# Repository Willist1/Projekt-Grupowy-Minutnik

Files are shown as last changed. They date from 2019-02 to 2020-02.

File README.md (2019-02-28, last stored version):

## Projekt Grupowy Minutnika dla prelegentów

Zadania stawiane porjektowi według strony projektów grupowych:

https://projektgrupowy.eti.pg.gda.pl/editions/12/projects/3469

 5@KSME'2019 Minutnik do odmierzania czasu prezentacji 1-99 minut

edycja: 2019

klient: dr hab. inż. Marek Wójcikowski prof. nadzw. PG (opiekun PG)

opiekun: dr hab. inż. Marek Wójcikowski prof. nadzw. PG (KSME)

kierownik: -

W ramach projektu powinien powstać projekt oraz prototyp
sprzętowego minutnika do odmierzania czasu trwania prezentacji. Wymagane cechy
urządzenia:

- odmierzanie czasu: 1-99 minut z rozdzielczością 1 sekundy;

- zasilanie bateryjne oraz 5V (USB), opcjonalnie akumulator z
ładowaniem w urządzeniu;

- duży i jasny wyświetlacz (wysokość cyfry >40mm);

- łatwe ustawianie czasu prezentacji;

- sygnalizacja dźwiękowa:

    - ostrzeżenie przed końcem prezentacji (czas wyprzedzenia
ustawiany przez użytkownika);

    - zakończenia prezentacji;

    - możliwość wyłączenia sygnalizacji ostrzeżenia raz
zakończenia;

- pamięć ustawień po wyłączeniu zasilania;

- kompaktowe rozmiary;

- atrakcyjny wygląd.

 Zakres pracy:

- zapoznanie się z istniejącymi rozwiązaniami i dostępnymi
wyświetlaczami;

- do realizacji minutnika można wykorzystać gotowy moduł
mikrokontrolera;

- zapoznanie się z istniejącymi mikrokontrolerami;

- opracowanie interfejsu użytkownika;

- napisanie oprogramowania mikrokontrolera;

- wykonanie i uruchomienie prototypu urządzenia;

- zaprojektowanie i wykonanie obudowy (np. w technologii druku
3D);

- napisanie dokumentacji.

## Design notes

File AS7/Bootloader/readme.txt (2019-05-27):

'breadboard' folder should be placed in:
C:\Program Files (x86)\Arduino\hardware

using AVRdude 6.3

To burn bootloader:
- connect USBasp to ATmega
- run 'NormalFuses'
- run 'BurnBootloader'

To upload program using bootloader:
- turn off supply voltage of ATmega
- draw PD7 to ground
- turn on supply voltage of ATmega
- run 'ArduinoBootloader'
- shortly after that set PD7 high

useful links:
- ATmega on breadboard: https://forum.mysensors.org/topic/3018/tutorial-how-to-burn-1mhz-8mhz-bootloader-using-arduino-ide-1-6-5-r5
- Verbose output on upload: https://forum.arduino.cc/index.php?topic=417659.0

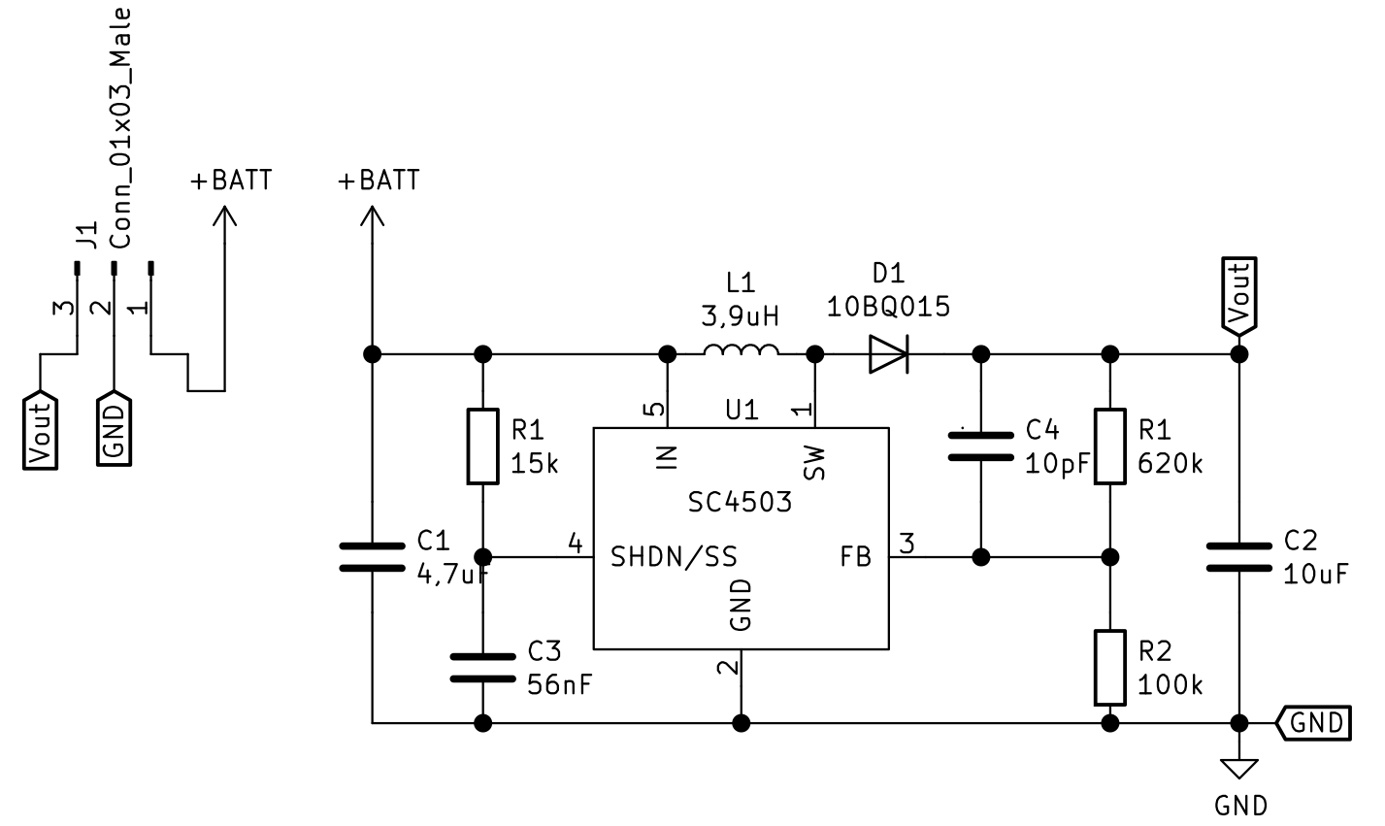
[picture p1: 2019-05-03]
Minutnix/BoostSchematic7V.png

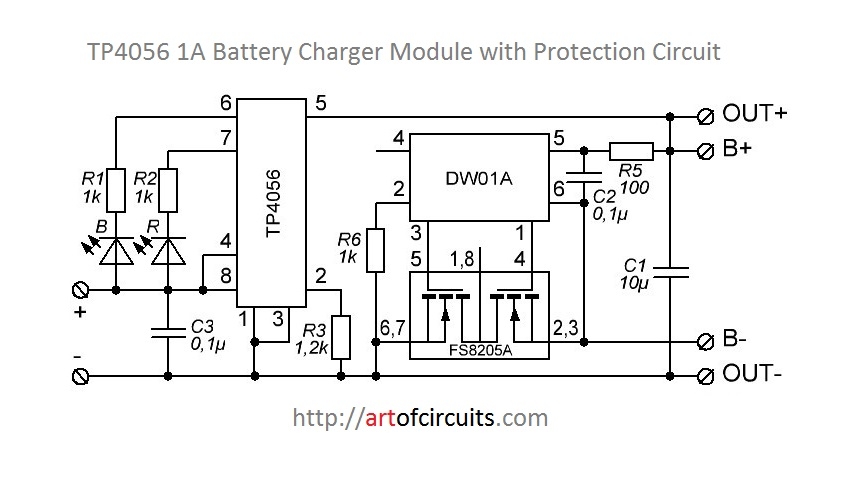
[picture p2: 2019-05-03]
Minutnix/ChargerSchematic.jpg

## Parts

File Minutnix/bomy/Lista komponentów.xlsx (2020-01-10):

Lista komponentów
Część | Package | Wartość/Model | Ilość
Rezystor | R0603 | 51 [Ω] | 30
Kondensator | C0603 | 100 n [F] | 11
Rezystor | R0603 | 1.2 k [Ω] | 1
Rezystor | R0603 | 4.7 k [Ω] | 11
Rezystor | R0603 | 220 [Ω] | 2
Kondensator | C0603 | 22 p [F] | 2
Kondensator | C1210 | 100 u [F] | 1
Rezystor | R0603 | 10 k [Ω] | 1
Kondensator | C0402 | 10 n [F] | 1
Kondensator | C1206 | 10 u [F] | 2
Dławik | DR73 | 10 u [H] | 1
Kondensator | SMC_B | 4.7 u [F] | 1
Kondensator | 153CLV-0810 | 470 u [F] | 1
Rezystor | R0603 | 820 [Ω] | 7
Dławik ferrytowy | R0604 | 100MHz: 330Ω | 1
Konektor | JST-XH-03 |  | 3
Konektor | FFC-0.5mm-12pin |  | 2
Wyświetlacz 7 segm. | OPD-S23010LR-BW |  | 4
Kwarc | SMD-2X6-CYL | 32.768 k [Hz] | 1
Przycisk | TACTILE_SWITCH_PTH_12MM |  | 5
Rejestr przesuwny | SO16 | TPIC6C596PW | 4
Dioda led | CHIPLED_0603 | zielona | 2
Dioda led | CHIPLED_0603 | czerwona | 2
Dioda led | CHIPLED_0603 | żółta | 3
Dioda led | LED5MM | czerwona | 2
Włącznik | mini isostat |  | 1
Regulator | SOT223 | LM1117 | 1
Regulator | Pololu 9 V regulator board | U3V12F9 | 1
Tranzystor | SOT23 | NPN | 1
Dioda Shottky | DO214AA |  | 1
Fotorezystor | GL5528 | 10-20 k [Ω] | 1
Złącze ISP | MA03-2 |  | 1
Potencjometr | Helitrim 3296Y | 10 k [Ω] | 1
Brzęczyk | HCM12 | 85 [dB] | 1
Enkoder | EC11 pionowy | 20 [imp/obr] | 1
Port microUSB | AUSB-1010-05S | typ B | 1
Kontroler | QFP80P900X900X120-32N | ATMEGA328P-AU | 1
Kontroler USB-UART | SSOP28 | FT232RL | 1
Ekspander | SO16W | PCF8574T | 1
Ładowarka | SOP-8 | TP4056 | 1

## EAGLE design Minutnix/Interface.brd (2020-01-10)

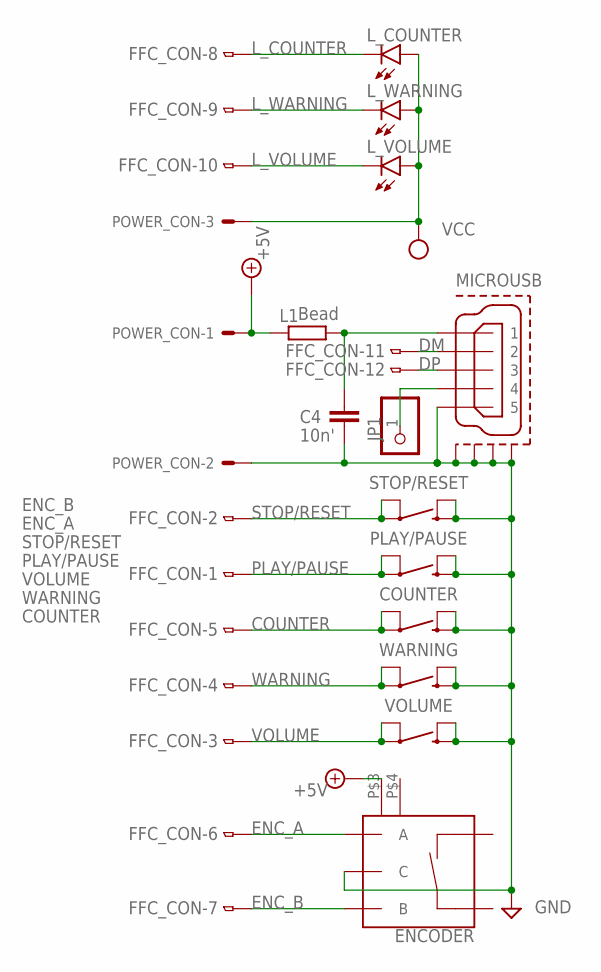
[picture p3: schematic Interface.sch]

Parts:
C4: 10n'; C0402
COUNTER: MOMENTARY-SWITCH-SPST-PTH-12MM; TACTILE_SWITCH_PTH_12MM
ENCODER: ENCODER-SWITCH; ROTARY_ENC_PLAIN
FFC_CON: FH12-12S-0.5S_THINNER; FH12-12S-0.5SH_THINER
JP1: PINHD-1X1; 1X01
L1: Bead; R0603
L_COUNTER: LEDCHIPLED_0805; CHIPLED_0805
L_VOLUME: LEDCHIPLED_0805; CHIPLED_0805
L_WARNING: LEDCHIPLED_0805; CHIPLED_0805
MICROUSB: MICRO-USB-RECEPTACLE; 47589-0002
PLAY/PAUSE: MOMENTARY-SWITCH-SPST-PTH-12MM; TACTILE_SWITCH_PTH_12MM
POWER_CON: JST-XH-03-PIN-LONG-PAD; JST-XH-03-PACKAGE-LONG-PAD
STOP/RESET: MOMENTARY-SWITCH-SPST-PTH-12MM; TACTILE_SWITCH_PTH_12MM
VOLUME: MOMENTARY-SWITCH-SPST-PTH-12MM; TACTILE_SWITCH_PTH_12MM
WARNING: MOMENTARY-SWITCH-SPST-PTH-12MM; TACTILE_SWITCH_PTH_12MM

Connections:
+5V: ENCODER.P$3 (GND1), L1.1, POWER_CON.1
COUNTER: COUNTER.1, COUNTER.2 (3), FFC_CON.5
DM: FFC_CON.11, MICROUSB.2
DP: FFC_CON.12, MICROUSB.3
ENC_A: ENCODER.A, FFC_CON.6
ENC_B: ENCODER.B, FFC_CON.7
GND: C4.2, COUNTER.3 (2), COUNTER.4, ENCODER.C, MICROUSB.5, MICROUSB.CASING1 (GND1), MICROUSB.CASING2 (GND2), MICROUSB.CASING3 (GND3), MICROUSB.CASING4 (GND4), PLAY/PAUSE.3 (2), PLAY/PAUSE.4, POWER_CON.2, STOP/RESET.3 (2), STOP/RESET.4, VOLUME.3 (2), VOLUME.4, WARNING.3 (2), WARNING.4
L_COUNTER: FFC_CON.8, L_COUNTER.C
L_VOLUME: FFC_CON.10, L_VOLUME.C
L_WARNING: FFC_CON.9, L_WARNING.C
unnamed: JP1.1, MICROUSB.4
unnamed: C4.1, L1.2, MICROUSB.1
PLAY/PAUSE: FFC_CON.1, PLAY/PAUSE.1, PLAY/PAUSE.2 (3)
STOP/RESET: FFC_CON.2, STOP/RESET.1, STOP/RESET.2 (3)
VCC: L_COUNTER.A, L_VOLUME.A, L_WARNING.A, POWER_CON.3
VOLUME: FFC_CON.3, VOLUME.1, VOLUME.2 (3)
WARNING: FFC_CON.4, WARNING.1, WARNING.2 (3)

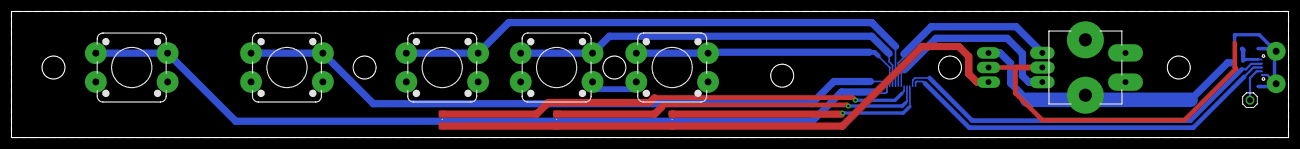
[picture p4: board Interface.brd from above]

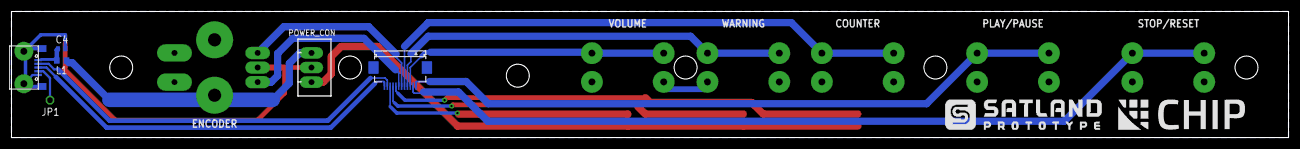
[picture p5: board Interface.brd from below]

Board: 2 copper layers, 222.3 x 21.9 mm, 15 parts (5 on the bottom side), 17 nets.

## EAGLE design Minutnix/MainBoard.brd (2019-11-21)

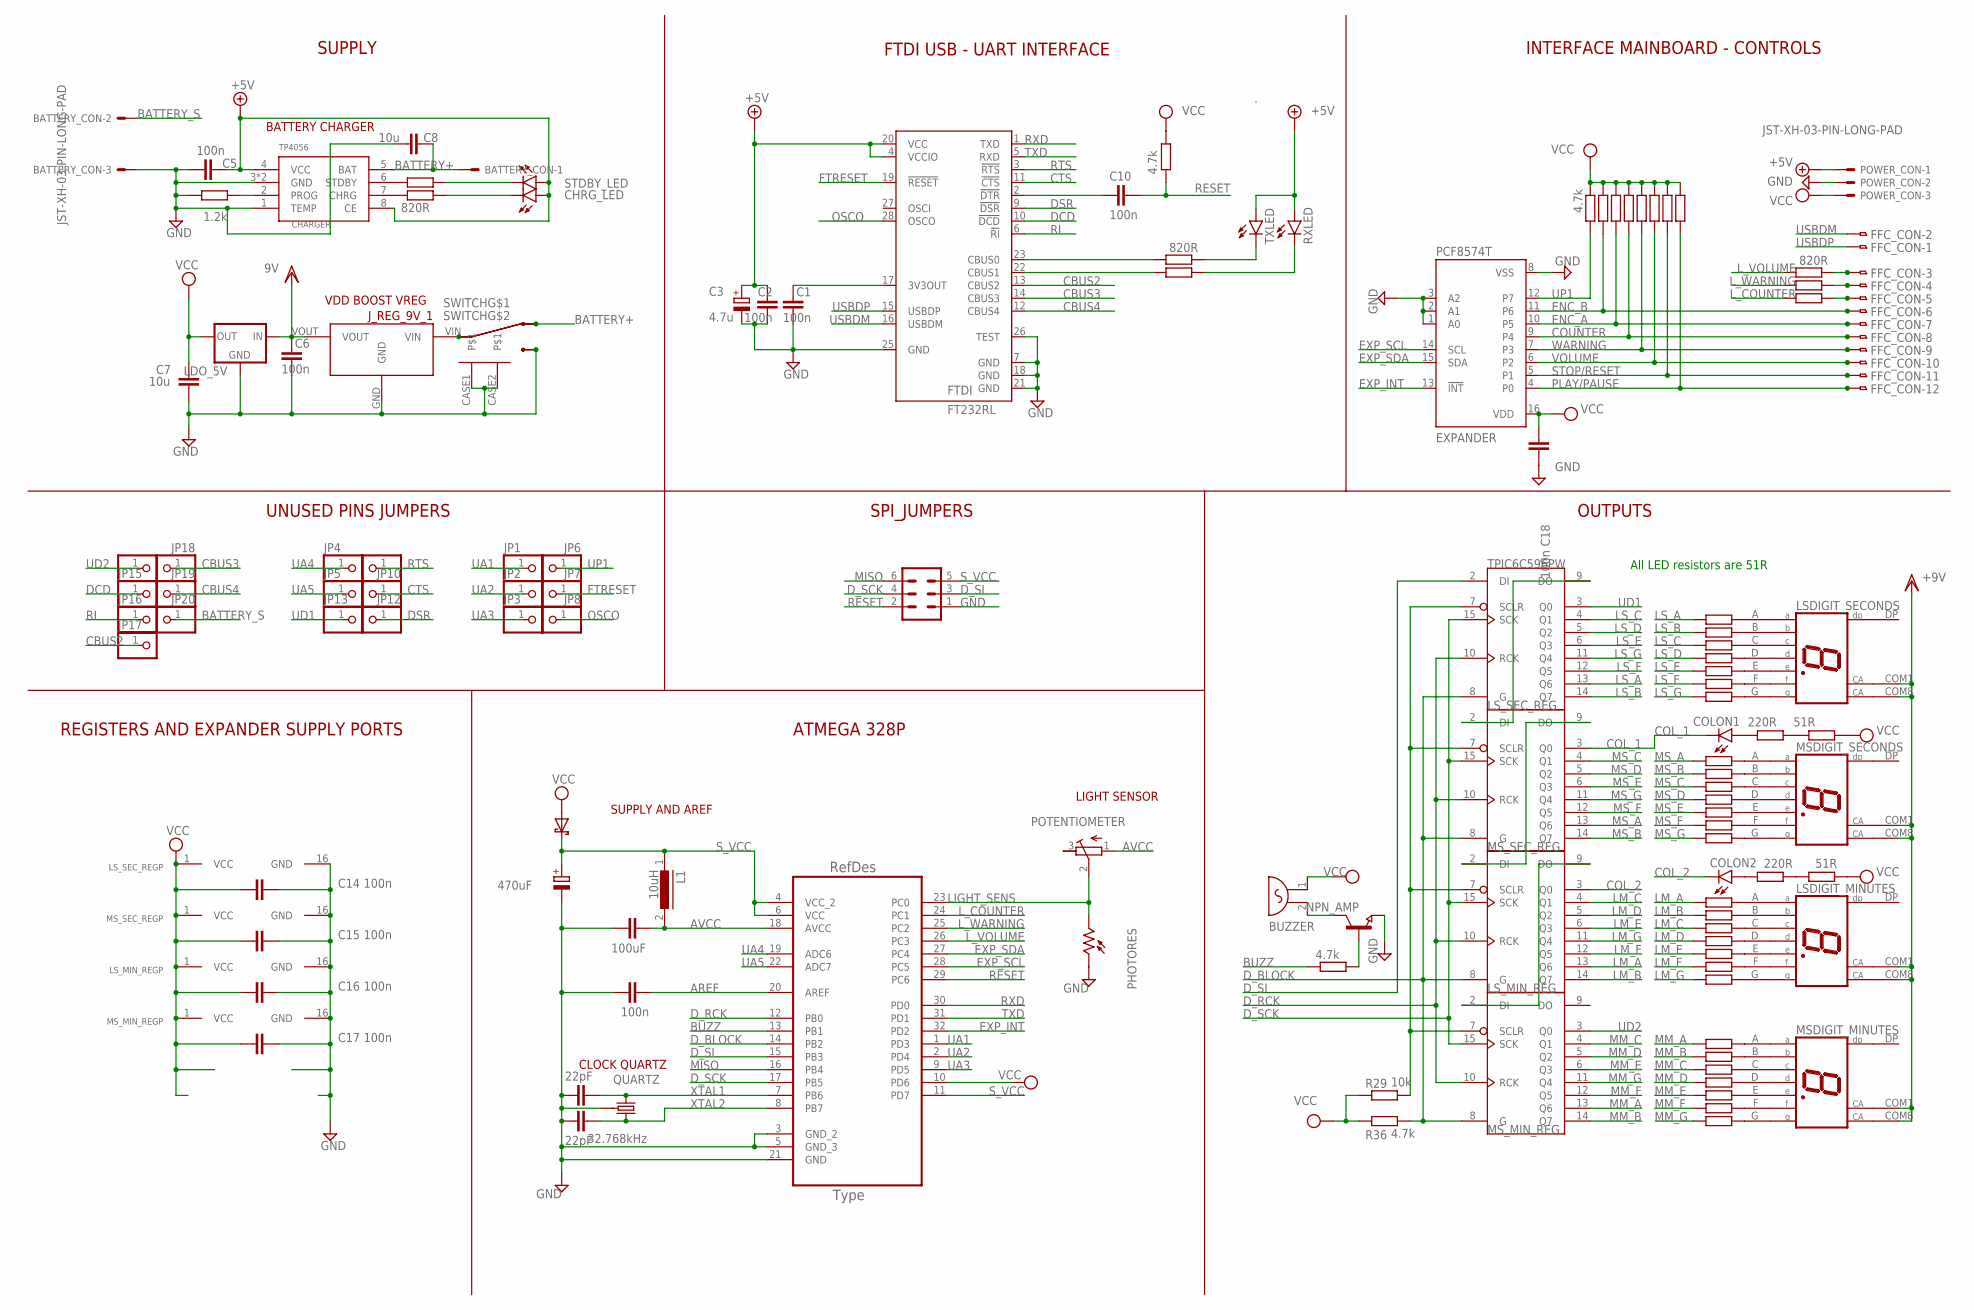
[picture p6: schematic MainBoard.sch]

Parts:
ATMEGA328P: ATMEGA328P-AU; QFP80P900X900X120-32N
BATTERY_CON: JST-XH-03-PIN-LONG-PAD; JST-XH-03-PACKAGE-LONG-PAD
BUZZER: F/HGP
C1, C2, C4, C5, C6, C10, C14, C15, C16, C17, C18: 100n; C0603
C3: 4.7u; SMC_B
C7, C8: 10u; C1206
C29, C30: 22pF; C0603
C31: 470uF; 153CLV-0810
C32: 100uF; C1210
CHARGER: TP4056; SOP-8
CHRG_LED: LEDCHIPLED_0603; CHIPLED_0603
COLON1, COLON2: LED5MM
EXPANDER: PCF8574T; SO16W
FFC_CON: FH12-12S-0.5S_THINNER; FH12-12S-0.5SH_THINER
FTDI: FT232RL; SSOP28
JP1, JP2, JP3, JP4, JP5, JP6, JP7, JP8, JP9, JP10, JP12, JP13, JP14, JP15, JP16, JP17, JP18, JP19, JP20: PINHD-1X1; 1X01
J_REG_9V_1: 9V_VOLTAGE_REGULATOR
L1: 10uH; DR73
LDO_5V: LM1117; SOT223
LSDIGIT_MINUTES: LED-7-SEGM-56MM; MYTHT
LSDIGIT_SECONDS: LED-7-SEGM-56MM; MYTHT
LS_MIN_REG: TPIC6C596PW; SO16
LS_SEC_REG: TPIC6C596PW; SO16
MSDIGIT_MINUTES: LED-7-SEGM-56MM; MYTHT
MSDIGIT_SECONDS: LED-7-SEGM-56MM; MYTHT
MS_MIN_REG: TPIC6C596PW; SO16
MS_SEC_REG: TPIC6C596PW; SO16
NPN_AMP: NPN-TRANSISTOR_SOT23; SOT23
PHOTORES: VT90N1; VT900
POTENTIOMETER: R-TRIMM3296Y; RTRIM3296Y
POWER_CON: JST-XH-03-PIN-LONG-PAD; JST-XH-03-PACKAGE-LONG-PAD
QUARTZ: 32.768kHz; CRYSTAL-SMD-2X6-CYL
R1, R2, R3, R4, R5, R6, R7, R8, R9, R10, R11, R12, R13, R14, R15, R16, R17, R18, R19, R20, R21, R22, R23, R24, R25, R26, R27, R28: 50; R0603
R29: 10k; R0603
R30, R31, R33, R36, R42, R43, R44, R45, R46, R56, R61: 4.7k; R0603
R32, R35: 51R; R0603
R34, R50: 220R; R0603
R39, R40, R47, R52, R64, R65, R66: 820R; R0603
R48: 1.2k; R0603
RXLED: LEDCHIPLED_0603; CHIPLED_0603
SHOTTKY: S2A; DO214AA
SPI_JUMPERS: MA03-2
STDBY_LED: LEDCHIPLED_0603; CHIPLED_0603
SWITCH: X2; MINI
TXLED: LEDCHIPLED_0603; CHIPLED_0603

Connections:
+5V: C2.2, C3.+, C5.1, CHARGER.4 (VCC), CHARGER.8 (CE), CHRG_LED.A, FTDI.4 (VCCIO), FTDI.20 (VCC), POWER_CON.1, RXLED.A, STDBY_LED.A, TXLED.A
AREF: ATMEGA328P.20 (AREF), C4.1
AVCC: ATMEGA328P.18 (AVCC), C32.1, L1.2, POTENTIOMETER.1 (A)
BATTERY+: BATTERY_CON.1, C8.2, CHARGER.5 (BAT), SWITCH.1, SWITCH.4
BATTERY_S: BATTERY_CON.2, JP20.1
BUZZ: ATMEGA328P.13 (PB1), R30.2
CBUS2: FTDI.13 (CBUS2), JP17.1
CBUS3: FTDI.14 (CBUS3), JP18.1
CBUS4: FTDI.12 (CBUS4), JP19.1
COL_1: COLON1.K (C), MS_SEC_REG.3 (Q0)
COL_2: COLON2.K (C), LS_MIN_REG.3 (Q0)
COUNTER: EXPANDER.9 (P4), FFC_CON.8, R42.2
CTS: FTDI.11 (!CTS), JP10.1
DCD: FTDI.10 (!DCD), JP15.1
DSR: FTDI.9 (!DSR), JP12.1
DTR: C10.2, FTDI.2 (!DTR)
D_BLOCK: ATMEGA328P.14 (PB2), LS_MIN_REG.8 (G), LS_SEC_REG.8 (G), MS_MIN_REG.8 (G), MS_SEC_REG.8 (G), R36.1
D_RCK: ATMEGA328P.12 (PB0), LS_MIN_REG.10 (RCK), LS_SEC_REG.10 (RCK), MS_MIN_REG.10 (RCK), MS_SEC_REG.10 (RCK)
D_SCK: ATMEGA328P.17 (PB5), LS_MIN_REG.15 (SCK), LS_SEC_REG.15 (SCK), MS_MIN_REG.15 (SCK), MS_SEC_REG.15 (SCK), SPI_JUMPERS.4
D_SI: ATMEGA328P.15 (PB3), LS_SEC_REG.2 (DI), SPI_JUMPERS.3
ENC_A: EXPANDER.10 (P5), FFC_CON.7, R33.2
ENC_B: EXPANDER.11 (P6), FFC_CON.6, R31.2
EXP_INT: ATMEGA328P.32 (PD2), EXPANDER.13 (!INT)
EXP_SCL: ATMEGA328P.28 (PC5), EXPANDER.14 (SCL)
EXP_SDA: ATMEGA328P.27 (PC4), EXPANDER.15 (SDA)
FTRESET: FTDI.19 (!RESET), JP7.1
GND: ATMEGA328P.3 (GND_2), ATMEGA328P.5 (GND_3), ATMEGA328P.21 (GND), BATTERY_CON.3, C1.1, C2.1, C3.-, C4.2, C5.2, C6.1, C7.2, C8.1, C14.1, C15.1, C16.1, C17.1, C18.1, C29.1, C30.1, C31.-, C32.2, CHARGER.1 (TEMP), CHARGER.3 (GND), CHARGER.ETP (GND), EXPANDER.1 (A0), EXPANDER.2 (A1), EXPANDER.3 (A2), EXPANDER.8 (VSS), FTDI.7 (GND), FTDI.18 (GND), FTDI.21 (GND), FTDI.25 (GND), FTDI.26 (TEST), J_REG_9V_1.GND, LDO_5V.1 (GND), LS_MIN_REG.16 (GND), LS_SEC_REG.16 (GND), MS_MIN_REG.16 (GND), MS_SEC_REG.16 (GND), NPN_AMP.2 (E), PHOTORES.1, POWER_CON.2, QUARTZ.SHEILD (GND), R48.2, SPI_JUMPERS.1, SWITCH.3, SWITCH.6, SWITCH.CASE1, SWITCH.CASE2
LIGHT_SENS: ATMEGA328P.23 (PC0), PHOTORES.2, POTENTIOMETER.2 (S)
LM_A: LS_MIN_REG.13 (Q6), R7.2
LM_B: LS_MIN_REG.14 (Q7), R6.2
LM_C: LS_MIN_REG.4 (Q1), R5.2
LM_D: LS_MIN_REG.5 (Q2), R4.2
LM_E: LS_MIN_REG.6 (Q3), R3.2
LM_F: LS_MIN_REG.12 (Q5), R2.2
LM_G: LS_MIN_REG.11 (Q4), R1.2
LS_A: LS_SEC_REG.13 (Q6), R21.2
LS_B: LS_SEC_REG.14 (Q7), R20.2
LS_C: LS_SEC_REG.4 (Q1), R19.2
LS_D: LS_SEC_REG.5 (Q2), R18.2
LS_E: LS_SEC_REG.6 (Q3), R17.2
LS_F: LS_SEC_REG.12 (Q5), R16.2
LS_G: LS_SEC_REG.11 (Q4), R15.2
L_COUNTER: ATMEGA328P.24 (PC1), R52.2
L_VOLUME: ATMEGA328P.26 (PC3), R64.2
L_WARNING: ATMEGA328P.25 (PC2), R47.2
MISO: ATMEGA328P.16 (PB4), SPI_JUMPERS.6
MM_A: MS_MIN_REG.13 (Q6), R27.2
MM_B: MS_MIN_REG.14 (Q7), R26.2
MM_C: MS_MIN_REG.4 (Q1), R25.2
MM_D: MS_MIN_REG.5 (Q2), R24.2
MM_E: MS_MIN_REG.6 (Q3), R23.2
MM_F: MS_MIN_REG.12 (Q5), R22.2
MM_G: MS_MIN_REG.11 (Q4), R28.2
MS_A: MS_SEC_REG.13 (Q6), R14.2
MS_B: MS_SEC_REG.14 (Q7), R13.2
MS_C: MS_SEC_REG.4 (Q1), R12.2
MS_D: MS_SEC_REG.5 (Q2), R11.2
MS_E: MS_SEC_REG.6 (Q3), R10.2
MS_F: MS_SEC_REG.12 (Q5), R9.2
MS_G: MS_SEC_REG.11 (Q4), R8.2
unnamed: R32.2, R50.1
unnamed: MSDIGIT_MINUTES.F, R22.1
unnamed: LSDIGIT_MINUTES.G, R1.1
unnamed: MSDIGIT_MINUTES.E, R23.1
unnamed: LSDIGIT_MINUTES.F, R2.1
unnamed: LSDIGIT_MINUTES.E, R3.1
unnamed: LSDIGIT_MINUTES.D, R4.1
unnamed: LSDIGIT_MINUTES.C, R5.1
unnamed: LSDIGIT_MINUTES.B, R6.1
unnamed: FFC_CON.3, R64.1
unnamed: MSDIGIT_MINUTES.D, R24.1
unnamed: FFC_CON.4, R47.1
unnamed: MSDIGIT_MINUTES.C, R25.1
unnamed: LS_MIN_REG.7 (SCLR), LS_SEC_REG.7 (SCLR), MS_MIN_REG.7 (SCLR), MS_SEC_REG.7 (SCLR), R29.1
unnamed: LSDIGIT_MINUTES.A, R7.1
unnamed: C1.2, FTDI.17 (3V3OUT)
unnamed: COLON2.A, R34.2
unnamed: FFC_CON.5, R52.1
unnamed: MSDIGIT_MINUTES.B, R26.1
unnamed: MSDIGIT_MINUTES.A, R27.1
unnamed: MSDIGIT_SECONDS.G, R8.1
unnamed: MSDIGIT_SECONDS.F, R9.1
unnamed: MSDIGIT_SECONDS.E, R10.1
unnamed: FTDI.23 (CBUS0), R66.2
unnamed: MSDIGIT_SECONDS.D, R11.1
unnamed: MSDIGIT_SECONDS.C, R12.1
unnamed: MSDIGIT_SECONDS.B, R13.1
unnamed: MSDIGIT_SECONDS.A, R14.1
unnamed: LSDIGIT_SECONDS.G, R15.1
unnamed: LSDIGIT_SECONDS.F, R16.1
unnamed: FTDI.22 (CBUS1), R65.2
unnamed: LSDIGIT_SECONDS.E, R17.1
unnamed: LSDIGIT_SECONDS.D, R18.1
unnamed: LSDIGIT_SECONDS.C, R19.1
unnamed: LSDIGIT_SECONDS.B, R20.1
unnamed: LSDIGIT_SECONDS.A, R21.1
unnamed: R34.1, R35.2
unnamed: CHARGER.7 (CHRG), R39.2
unnamed: CHARGER.6 (STDBY), R40.2
unnamed: CHRG_LED.C, R39.1
unnamed: R40.1, STDBY_LED.C
unnamed: COLON1.A, R50.2
unnamed: MSDIGIT_MINUTES.G, R28.1
unnamed: R66.1, TXLED.C
unnamed: NPN_AMP.1 (B), R30.1
unnamed: BUZZER.2, NPN_AMP.3 (C)
unnamed: R65.1, RXLED.C
unnamed: LS_MIN_REG.2 (DI), MS_SEC_REG.9 (DO)
unnamed: LS_MIN_REG.9 (DO), MS_MIN_REG.2 (DI)
unnamed: LS_SEC_REG.9 (DO), MS_SEC_REG.2 (DI)
unnamed: J_REG_9V_1.VIN, SWITCH.2, SWITCH.5
unnamed: CHARGER.2 (PROG), R48.1
OSCO: FTDI.28 (OSCO), JP8.1
PLAY/PAUSE: EXPANDER.4 (P0), FFC_CON.12, R46.2
RESET: ATMEGA328P.29 (PC6), C10.1, R56.1, SPI_JUMPERS.2
RI: FTDI.6 (!RI), JP16.1
RTS: FTDI.3 (!RTS), JP9.1
RXD: ATMEGA328P.30 (PD0), FTDI.1 (TXD)
STOP/RESET: EXPANDER.5 (P1), FFC_CON.11, R45.2
S_VCC: ATMEGA328P.4 (VCC_2), ATMEGA328P.6 (VCC), ATMEGA328P.11 (PD7), C31.+, L1.1, SHOTTKY.C, SPI_JUMPERS.5
TXD: ATMEGA328P.31 (PD1), FTDI.5 (RXD)
UA1: ATMEGA328P.1 (PD3), JP1.1
UA2: ATMEGA328P.2 (PD4), JP2.1
UA3: ATMEGA328P.9 (PD5), JP3.1
UA4: ATMEGA328P.19 (ADC6), JP4.1
UA5: ATMEGA328P.22 (ADC7), JP5.1
UD1: JP13.1, LS_SEC_REG.3 (Q0)
UD2: JP14.1, MS_MIN_REG.3 (Q0)
UP1: EXPANDER.12 (P7), JP6.1, R61.2
USBDM: FFC_CON.2, FTDI.16 (USBDM)
USBDP: FFC_CON.1, FTDI.15 (USBDP)
VCC: ATMEGA328P.10 (PD6), BUZZER.1, C7.1, C14.2, C15.2, C16.2, C17.2, C18.2, EXPANDER.16 (VDD), LDO_5V.2 (OUT), LDO_5V.4 (OUT), LS_MIN_REG.1 (VCC), LS_SEC_REG.1 (VCC), MS_MIN_REG.1 (VCC), MS_SEC_REG.1 (VCC), POWER_CON.3, R29.2, R31.1, R32.1, R33.1, R35.1, R36.2, R42.1, R43.1, R44.1, R45.1, R46.1, R56.2, R61.1, SHOTTKY.A
VDD: C6.2, J_REG_9V_1.VOUT, LDO_5V.3 (IN), LSDIGIT_MINUTES.COM1 (CA1), LSDIGIT_MINUTES.COM8 (CA8), LSDIGIT_SECONDS.COM1 (CA1), LSDIGIT_SECONDS.COM8 (CA8), MSDIGIT_MINUTES.COM1 (CA1), MSDIGIT_MINUTES.COM8 (CA8), MSDIGIT_SECONDS.COM1 (CA1), MSDIGIT_SECONDS.COM8 (CA8)
VOLUME: EXPANDER.6 (P2), FFC_CON.10, R44.2
WARNING: EXPANDER.7 (P3), FFC_CON.9, R43.2
XTAL1: ATMEGA328P.7 (PB6), C29.2, QUARTZ.X2 (2)
XTAL2: ATMEGA328P.8 (PB7), C30.2, QUARTZ.X1 (1)

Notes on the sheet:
All LED resistors are 51R
LIGHT SENSOR
INTERFACE MAINBOARD - CONTROLS
FTDI USB - UART INTERFACE
UNUSED PINS JUMPERS
SUPPLY AND AREF
CLOCK QUARTZ
VDD BOOST VREG
REGISTERS AND EXPANDER SUPPLY PORTS
BATTERY CHARGER
SUPPLY
ATMEGA 328P
OUTPUTS

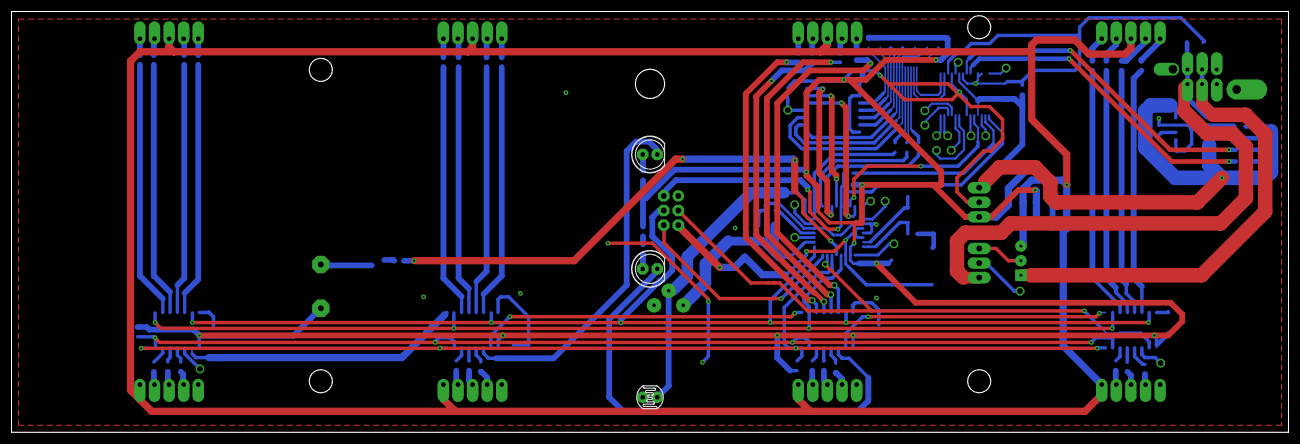
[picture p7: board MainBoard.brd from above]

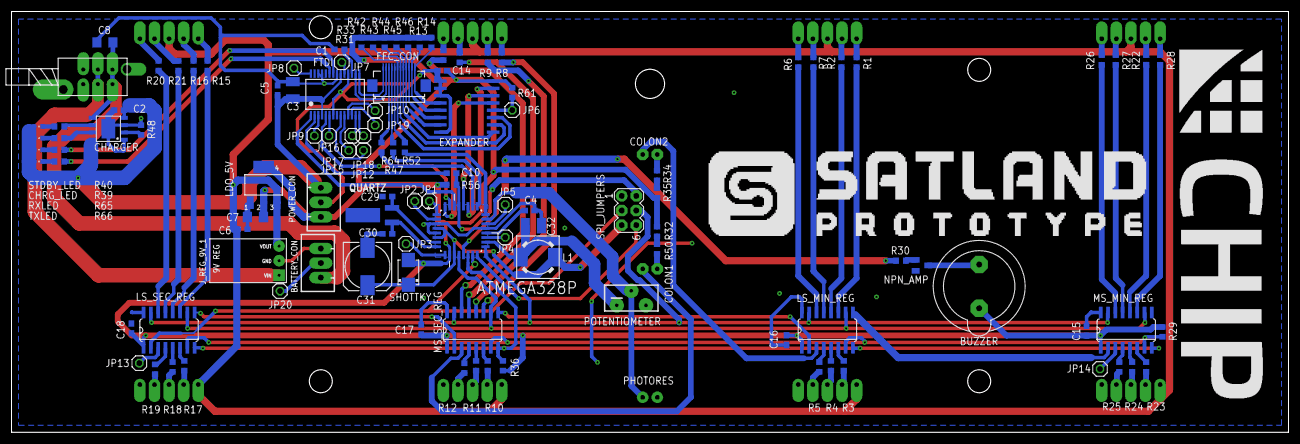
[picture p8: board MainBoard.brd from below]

Board: 2 copper layers, 222.3 x 73.3 mm, 121 parts (114 on the bottom side), 137 nets.

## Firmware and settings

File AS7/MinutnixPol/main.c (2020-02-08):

/*
 *  main.c
 *
 *  Created: 2019-03-09 15:34
 *  Authors: Kluczek, Wegrzyn, Jopek
 */ 
//#define F_CPU 8000000L

#include <avr/io.h>
#include <avr/interrupt.h>
#include <avr/sleep.h>
#include <avr/wdt.h>
#include <util/delay.h>
#include <util/atomic.h>
#include <avr/pgmspace.h>
#include <stdbool.h>
#include <stdio.h>
#include "main.h"
#include "uart.h"
#include "display.h"
#include "i2c.h"
#include "PCF8574.h"
#include "encoder.h"
#include "buzzer.h"
#include "pwrFail.h"
#include "TPIC6C596.h"
#include "lightsensor.h"


#define EXTERNAL_CLOCK

#ifdef EXTERNAL_CLOCK
#define MAX_NO_ACTIVITY_TICKS 600	// 5 min
#else
#define MAX_NO_ACTIVITY_TICKS 300000	// 5 min
#endif

tSTATE currentState = sSetting;
volatile uint32_t ticks = 0;
volatile uint8_t toggle_500ms = 0;
uint32_t lastActivityTime = 0;
uint8_t WARN_MAX_VAL = 15;

#define ALARM_MAX_DURATION 20 // [s]
volatile uint8_t alarmTick = 0;
volatile bool endBeep = false;

// index of brightnessTable is ADC reading (max 255) divided by 9
// results range: 0-28 (29 values)
#define ADC_READING_DIVISOR 9
const uint8_t __attribute__((__progmem__)) brightnessTable[] = {
	//100, 55, 35, 30, 26, 24, 22, 20, 19, 18, 17, 16, 15, 14, 9, 5, 2, 1, 1, 1
	100, 70, 55, 42, 35, 33, 30, 28, 26, 25, 24, 23, 22, 21, 20, 19, 18, 17, 16, 15, 14, 13, 8, 5, 2, 1, 1, 1, 1
};

void sysTickInit()
{
	#ifdef EXTERNAL_CLOCK
	ASSR |= _BV(AS2);		// TIM2 tacted asynchronously
	TCCR2B = _BV(CS22);		// Preskaler CLKIO/64  (32.768 kHz / 256 / 64 = 2 Hz)
	#else //internal
	TCCR2A = _BV(WGM20);	//PWM, Phase Correct TOP = OCRA, OVint at BOTTOM
	OCR2A = 124;
	TCCR2B = _BV(WGM22) | _BV(CS21) | _BV(CS20);	// Preskaler CLKIO/32  (8 MHz / (124+1) / 32 /2 = 1 kHz)
	#endif
	
	while(ASSR & 0x1F);		// Wait for TIM2 update (busy flags must be cleared)
	TIMSK2 |= _BV(TOIE2);	// Unblock TIM2 overflow interrupt
}

void sysTickOn()
{
	TIMSK2 |= _BV(TOIE2);	// Unblock TIM2 overflow interrupt
}

void sysTickOff()
{
	TIMSK2 &= ~_BV(TOIE2);	// Block TIM2 overflow interrupt
}

ISR(TIMER2_OVF_vect)	// System clock
{
	ticks++;
	
	#ifdef EXTERNAL_CLOCK
	toggle_500ms ^= 0x01;
	if (!(ticks % 2) && (currentState == sRunning)) {
		if(NVData.totalSeconds > 0) NVData.totalSeconds--;
		if(endBeep && (alarmTick < ALARM_MAX_DURATION)) alarmTick++;
	}
	#else
	if (!(ticks % 500)) {
		toggle_500ms ^= 0x01;
	}
	if (!(ticks % 1000) && (currentState == sRunning)) {
		if(NVData.totalSeconds > 0) NVData.totalSeconds--;
		if(endBeep && (alarmTick < ALARM_MAX_DURATION)) alarmTick++;
	}
	#endif
	
	// ADJUST BRIGHTNESS
	uint8_t brightness = 0;
	memcpy_P(&brightness,brightnessTable+(lightsensorRead()/ADC_READING_DIVISOR),1);
	brightness = lightsensorFilter(brightness);
	displaySetBrightness(brightness);
}

void wdtInit() {
	MCUSR &= ~_BV(WDRF);	// Clear watchdog system reset flag
	wdt_reset();
	WDTCSR = _BV(WDCE) | _BV(WDE);
	wdt_enable(WDTO_1S);
}

void wdtDeinit() {
	MCUSR &= ~_BV(WDRF);
	wdt_reset();
	wdt_disable();
}

#define SETTINGS_LED_PORT PORTC
#define LED_SET_CNT 1
#define LED_SET_WARN 2
#define LED_SET_VOL 3

void settingsLEDInit() {
	DDRC |= (_BV(LED_SET_CNT) | _BV(LED_SET_WARN) | _BV(LED_SET_VOL));	// LED pins as output
	PORTC |= (_BV(LED_SET_CNT) | _BV(LED_SET_WARN) | _BV(LED_SET_VOL));	// Set all pins high (turn off LEDs)
}

void settingsLEDTurnOff() {
	PORTC |= (_BV(LED_SET_CNT) | _BV(LED_SET_WARN) | _BV(LED_SET_VOL));	// Turn off all LEDs
}

void settingsLEDToggle(uint8_t LEDId) {
	settingsLEDTurnOff();
	if (LEDId >= LED_SET_CNT && LEDId <= LED_SET_VOL) PORTC &= ~_BV(LEDId);	// Turn given LED on
}


BUTTON pressedButton = BUTTON_NONE;
BUTTON memorizedButton = setCnt;
uint8_t setVal = 0;
uint8_t valMax = 0;
uint8_t valMin = 0;

int main()
{
	displayOff();
	set_sleep_mode(SLEEP_MODE_IDLE);	// CPU clock turned off, peripherals operating normally
	
	//USART_init();
	//static FILE usartout = FDEV_SETUP_STREAM (put, get, _FDEV_SETUP_RW);
	//stdout = &usartout;
	
	PCF8574_Init();
	
	sysTickInit();
	TPIC6C596Init();
	pwrFailInit();
	settingsLEDInit();
	lightsensorInit();
	displayInit();
	buzzerInit();

	LEDDIGITS[0]= BLANK_DISPLAY;
	LEDDIGITS[1]= BLANK_DISPLAY;
	LEDDIGITS[2]= BLANK_DISPLAY;
	LEDDIGITS[3]= BLANK_DISPLAY;
	
	NVDataInit();
	if (NVData.config.cntVal > CNT_MAX_VAL) NVData.config.cntVal = CNT_MAX_VAL;
	WARN_MAX_VAL = NVData.config.cntVal;
	if (NVData.config.warnVal > WARN_MAX_VAL) NVData.config.warnVal = WARN_MAX_VAL;
	if (NVData.config.volumeVal > VOL_MAX_VAL) NVData.config.volumeVal = VOL_MAX_VAL;
	if (NVData.totalSeconds > NVData.config.cntVal*60) NVData.totalSeconds = NVData.config.cntVal*60;
	displaySetBrightness(DEFAULT_BRIGHTNESS);
	buzzerSetVolume(NVData.config.volumeVal);
	settingsLEDToggle(LED_SET_CNT);
	setVal = NVData.config.cntVal;	// prepare user interaction
	
	sei();
	SPDR = 0;				// Initialize SPI interrupts by writing to SPI data register
	while (SeqNum != 3);	// Wait for first SPI transfer to finish before enabling display
	while (SeqNum != 0);
	displayOn();
	
	wdtInit();
	wdt_reset();	// reset watchdog
	
	while(1)
	{
		// HANDLE EXPANDER INTERRUPT
		if (PCF8574_INT) {
			_delay_ms(1);			// debouncing
			PCF8574_ReadState();
			ATOMIC_BLOCK (ATOMIC_FORCEON) {
				
				lastActivityTime = ticks;							// set last activity timestamp
				
				// READ BUTTONPRESS
				pressedButton = PCF8574_ReadButtonPress();
				
				if (pressedButton != BUTTON_NONE) {					// button was pressed

					if (currentState == sSetting) {
						
						if (pressedButton != memorizedButton) {	// ON BUTTON CHANGE
							
							// ESTABLISH NEW STATE
							switch(pressedButton)
							{
								case setCnt:
								case setWarning:
								case setVolume:
								case Stop:
									currentState = sSetting;
									break;
								case Play:
									currentState = sRunning;
									settingsLEDTurnOff();
									break;
								default:
									break;
							}
							
							// SAVE SETTINGS
							switch(memorizedButton)
							{
								case setCnt:
									NVData.config.cntVal = setVal;
									NVData.totalSeconds = NVData.config.cntVal*60;
									break;
								case setWarning:
									NVData.config.warnVal = setVal;
									break;
								case setVolume:
									NVData.config.volumeVal = setVal;
									buzzerOff();
									break;
								default:
									break;
							}
							
							// MEMORIZE BUTTON PRESS
							memorizedButton = pressedButton;
							
							// PREPARE INTERACTION WITH USER
							switch(pressedButton)
							{
								case setCnt:
									setVal = NVData.config.cntVal;
									settingsLEDToggle(LED_SET_CNT);
									break;
								case setWarning:
									// prevent warning time from being greater than total time
									WARN_MAX_VAL = NVData.config.cntVal;
									if (NVData.config.warnVal > NVData.config.cntVal) NVData.config.warnVal = NVData.config.cntVal;
									setVal = NVData.config.warnVal;
									settingsLEDToggle(LED_SET_WARN);
									break;
								case setVolume:
									setVal = NVData.config.volumeVal;
									settingsLEDToggle(LED_SET_VOL);
									buzzerOn();
									break;
								case Stop:
									NVData.totalSeconds = NVData.config.cntVal*60;
									setVal = NVData.config.cntVal;
									settingsLEDToggle(LED_SET_CNT);
									memorizedButton = setCnt;
									buzzerOff();
									break;
								default:
									break;
							}
							
						}
						
					} else { // (currentState == sRunning || currentState == sPause)
						
						// ESTABLISH NEW STATE
						switch(pressedButton)
						{
							case Stop:
								memorizedButton = Stop;
								currentState = sSetting;
								NVData.totalSeconds = NVData.config.cntVal*60;
								setVal = NVData.config.cntVal;
								settingsLEDToggle(LED_SET_CNT);
								memorizedButton = setCnt;
								endBeep = false;
								alarmTick = 0;
								buzzerOff();
								break;
							case Play:
								if (currentState == sRunning) {
									if (NVData.totalSeconds > 0)
										currentState = sPause;
									else {
										memorizedButton = Stop;
										currentState = sSetting;
										NVData.totalSeconds = NVData.config.cntVal*60;
										setVal = NVData.config.cntVal;
										settingsLEDToggle(LED_SET_CNT);
										memorizedButton = setCnt;
										endBeep = false;
										alarmTick = 0;
										buzzerOff();
									}
										
								} else { // currentState == sPause
									currentState = sRunning;
								}
								break;
							default:
								break;
						}
						
					}
					
				}
				
				// READ ENCODER
				switch (memorizedButton) {
					case setCnt:
						valMax = CNT_MAX_VAL;
						valMin = CNT_MIN_VAL;
						break;
					case setWarning:
						valMax = WARN_MAX_VAL;
						valMin = WARN_MIN_VAL;
						break;
					case setVolume:
						valMax = VOL_MAX_VAL;
						valMin = VOL_MIN_VAL;
						break;
					default:
						valMax = 0;
						valMin = 0;
						break;
				}
				switch(Read2StepEncoder())
				{
					case -1 :	if(setVal>valMin) setVal-=1; break;
					case 0  :	break;
					case 1  :	if(setVal<valMax) setVal+=1; break;
				};
				
				PCF8574_INT = false;	// clear internal INT flag
			};
		}

		// DISPLAY UPDATE
		switch(currentState)
		{		
			case sSetting:
				ATOMIC_BLOCK (ATOMIC_FORCEON) {
					LEDDIGITS[0]= (uint8_t)(setVal/10);
					LEDDIGITS[1]= (uint8_t)((setVal%10));
					LEDDIGITS[2]= BLANK_DISPLAY;
					LEDDIGITS[3]= BLANK_DISPLAY;
				};
				switch (memorizedButton) {
					case setVolume:
						ATOMIC_BLOCK (ATOMIC_FORCEON) { buzzerSetVolume(setVal); };
						break;
					default:
						break;
				}
				break;
				
			case sRunning:
			if (NVData.totalSeconds > 0) {
				ATOMIC_BLOCK (ATOMIC_FORCEON) {
					LEDDIGITS[0]= (uint8_t)((NVData.totalSeconds/60)/10);
					LEDDIGITS[1]= (uint8_t)((NVData.totalSeconds/60)%10);
					LEDDIGITS[2]= (uint8_t)((NVData.totalSeconds%60)/10);
					LEDDIGITS[3]= (uint8_t)((NVData.totalSeconds%60)%10);
					if (toggle_500ms) {
						LEDDIGITS[1] |= DP;				// colon blink
						LEDDIGITS[2] |= DP;
					}
					else {
						LEDDIGITS[1] &= ~DP;
						LEDDIGITS[2] &= ~DP;
					}
				};
			} else {	// NVData.totalSeconds == 0
				if (toggle_500ms) {						// digits blink
					ATOMIC_BLOCK (ATOMIC_FORCEON) {
						LEDDIGITS[0]= 0;
						LEDDIGITS[1]= DP;
						LEDDIGITS[2]= DP;
						LEDDIGITS[3]= 0;
					};
				}
				else {
					ATOMIC_BLOCK (ATOMIC_FORCEON) {
						LEDDIGITS[0]= BLANK_DISPLAY;
						LEDDIGITS[1]= BLANK_DISPLAY;
						LEDDIGITS[2]= BLANK_DISPLAY;
						LEDDIGITS[3]= BLANK_DISPLAY;
					};
				}
			}
			
			if (NVData.totalSeconds == 0) {
				if (alarmTick < ALARM_MAX_DURATION)
				{
					buzzerOn();	// Perform continuous end beep
					endBeep = true;
				}
				else
				{
					buzzerOff();
				}
			} else if (NVData.totalSeconds == NVData.config.warnVal*60) {								// Start warn beep
				ATOMIC_BLOCK (ATOMIC_FORCEON) { buzzerOn(); };
			} else if (NVData.totalSeconds == NVData.config.warnVal*60 - WARN_BEEP_DURATION_SECONDS) {	// End warn beep
				ATOMIC_BLOCK (ATOMIC_FORCEON) { buzzerOff(); };
			}
			
			break;
			
			case sPause: //copy of old sRunning
			if (NVData.totalSeconds > 0) {
				ATOMIC_BLOCK (ATOMIC_FORCEON) 
					if (toggle_500ms) {						// digits blink
						ATOMIC_BLOCK (ATOMIC_FORCEON) {
							LEDDIGITS[0]= (uint8_t)((NVData.totalSeconds/60)/10);
							LEDDIGITS[1]= (uint8_t)((NVData.totalSeconds/60)%10) | DP;
							LEDDIGITS[2]= (uint8_t)((NVData.totalSeconds%60)/10) | DP;
							LEDDIGITS[3]= (uint8_t)((NVData.totalSeconds%60)%10);
						};
					}
					else {
						ATOMIC_BLOCK (ATOMIC_FORCEON) {
							LEDDIGITS[0]= BLANK_DISPLAY;
							LEDDIGITS[1]= BLANK_DISPLAY;
							LEDDIGITS[2]= BLANK_DISPLAY;
							LEDDIGITS[3]= BLANK_DISPLAY;
						};
					}
				};
			
			break;
			
			default:
				break;
				
		}
		
		// SLEEP MODE CHECK
		if ((ticks - lastActivityTime > MAX_NO_ACTIVITY_TICKS) && (currentState == sSetting)) {
			ATOMIC_BLOCK (ATOMIC_FORCEON) {		// turn off all interrupt sources except INT0
				displayOff();
				buzzerOff();
				settingsLEDTurnOff();
				lightsensorSuspend();
				TPIC6C596Suspend();
				wdtDeinit();
				LEDDIGITS[1] &= ~DP;			// turn off colon
				LEDDIGITS[2] &= ~DP;
				sysTickOff();
				switch(memorizedButton)			// save temporary config
				{
					case setCnt:
						NVData.config.cntVal = setVal;
						break;
					case setWarning:
						NVData.config.warnVal = setVal;
						break;
					case setVolume:
						NVData.config.volumeVal = setVal;
						break;
					default:
						break;
				}
				EEPROMupdate();	// only writes to EEPROM when config changed in relation to last record
			};
			sleep_mode();
			ATOMIC_BLOCK (ATOMIC_FORCEON) {		// restore all turned off interrupt sources
				sysTickOn();
				wdtInit();
				currentState = sSetting;		// enforce setting state
				memorizedButton = setCnt;		// memorized button
				setVal = NVData.config.cntVal;	// prepare user interaction
				ATOMIC_BLOCK (ATOMIC_FORCEON) {
					LEDDIGITS[0]= (uint8_t)(setVal/10);
					LEDDIGITS[1]= (uint8_t)((setVal%10));
					LEDDIGITS[2]= BLANK_DISPLAY;
					LEDDIGITS[3]= BLANK_DISPLAY;
				};
				TPIC6C596Resume();
				lightsensorResume();
				settingsLEDToggle(LED_SET_CNT);
				displayOn();
				lastActivityTime = ticks;		// activity timestamp
				PCF8574_INT = false;			// ignore wake-up cause (button press / encoder movement)
			};
		}

		wdt_reset();	// reset watchdog
	}

}

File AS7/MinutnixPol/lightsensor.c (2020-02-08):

/*8 bit 
 * lightsensor.c
 *
 * Created: 4/27/2019 8:48:28 PM
 *  Author: stefa
 */ 

#include "lightsensor.h"
#include <avr/io.h>

#define VREF 5

#define MA_FILTER_LENGTH   16    // must be power of 2^n
#define MA_FILTER_SHIFT    4     // n from above comment

void lightsensorInit() {
	ADMUX = _BV(REFS0) | _BV(ADLAR);	// Reference voltage equal to AVcc, multiplexer input 0, align result to the left (8-bit ADC)
	DIDR0 = _BV(ADC0D);					// Turn off digital function of pin nr 0
	ADCSRB = 0;							// Free running mode
	ADCSRA = _BV(ADEN) | _BV(ADATE) | _BV(ADPS2) | _BV(ADPS1) | _BV(ADPS0);
	// Turn on ADC and external trigger, prescaler ADC - 128 (16 MHz / 128)
	ADCSRA |= _BV(ADSC);				// Start conversions in free running mode
}

uint8_t lightsensorRead() {
	return ADCH;
}

void lightsensorSuspend() {
	ADCSRA &= ~(_BV(ADEN) | _BV(ADATE));	// Turn off ADC and external trigger
}

void lightsensorResume() {
	ADCSRA |= _BV(ADEN) | _BV(ADATE);	// Turn on ADC and external trigger
	ADCSRA |= _BV(ADSC);				// Start conversions in free running mode
}

uint8_t lightsensorFilter( uint8_t input ) {
	
	static uint8_t filterMemory[MA_FILTER_LENGTH] = { [0 ... MA_FILTER_LENGTH-1] = DEFAULT_BRIGHTNESS }; 
	static uint8_t sampleIdx = 0;
	static uint16_t accumulator = MA_FILTER_LENGTH * DEFAULT_BRIGHTNESS;
	
	accumulator += input;
	if ( accumulator > filterMemory[sampleIdx] )
		accumulator -= filterMemory[sampleIdx];
	else
		accumulator = 0;
	
	filterMemory[sampleIdx] = input;
	sampleIdx++;
	if ( sampleIdx == MA_FILTER_LENGTH ) sampleIdx = 0;
	
	return ( accumulator >> MA_FILTER_SHIFT );
}

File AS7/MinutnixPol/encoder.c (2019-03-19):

/*
 * encoder.c
 *
 * Created: 3/13/2019 9:00:40 PM
 *  Author: stefan
 */ 

#include <stdint.h>
#include "PCF8574.h"

int8_t enc_delta;

void ReadEncoder()
{
	static int8_t last;
	int8_t newpos, diff;

	newpos=0;
	if((PCF8574_PinState & SigAMask)==0) newpos=3;
	if((PCF8574_PinState & SigBMask)==0) newpos^=1;  // konwersja kodu Graya na binarny
	diff=last-newpos;
	if(diff & 1)
	{									// bit 0 = krok
		last=newpos;
		enc_delta+=(diff & 2)-1;		//bit 1 - kierunek
	}
}

int8_t Read1StepEncoder()
{
	ReadEncoder();
	int8_t val=enc_delta;
	enc_delta=0;
	return val;
}

int8_t Read2StepEncoder()
{
	ReadEncoder();
	int8_t val=enc_delta;
	enc_delta=val & 1;
	return val>>1;
}

int8_t Read4StepEncoder()
{
	ReadEncoder();
	int8_t val=enc_delta;
	enc_delta=val & 3;
	return val>>2;
}

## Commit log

2019-03-10 Schematic first draft
    [Ekspander.brd, Ekspander.sch, MainBoard.sch]
2019-03-10 Added new AS7 project
    Implemented functionalities:
    - 7-seg display multiplexing (with dimming)
    - communication with PCF8574 expander
    - external interrupt from expander detection
    - added source code for usart debug via std stream
2019-03-13 Added functions for reading and interpreting encoder signals
    Additionally fixed digit mapping
    [PCF8574.c, PCF8574.h, encoder.c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]
2019-03-14 Implemented SysTick and PWM for buzzer volume control
    [buzzer.c, display.c, main.c]
2019-03-14 Prepared power failure handling code
    [main.c, pwrFail.c]
2019-03-21 Main board V1
    [Ekspander.brd, Ekspander.sch, MainBoard.sch]
2019-03-21 First draft of board (correct displays)
    Resistors and capacitors not chosen yet,
    Goldpin on battery removed - will be directly on board
    [MainBoard.brd, MainBoard.sch]
2019-03-23 Prepared pwr failure detection
    [PCF8574.c, main.c, pwrFail.c]
2019-03-23 Adjusted pinout in code to electronic schematic
2019-03-24 Small corrections
    Disabling watchdog in sleep mode
    [main.c]
2019-03-24 Corretcion
    Corrected max no activity time
    [main.c]
2019-03-24 Fixed fwr fail procedure and brightness setting
    [display.c, pwrFail.c]
2019-03-24 Fixed dot jitter in running state, remove dot blining in setting state
    [main.c, pwrFail.c]
2019-03-27 Add First Draft of 3D model
    For documentation of first prototype.
    [AssUpper.0001.iam, AssUpper.iam, Assembly.0001.iam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]
2019-03-29 Wersja 1
    Do kubełka 1
    [Ekspander.sch, MainBoard.sch]
2019-04-03 Archivisation and actualisation
    Archivisation of 1 version of boards
    New version of boards
    [Assembly.stl, Ekspander.brd, Ekspander.sch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]
2019-04-28 New menu engine, implemented light sensor, added setting leds, piezo beeper control
2019-04-28 Fixed issue with brightness control after startup
    [display.c]
2019-04-28 Minor board changes
    [MainBoard.brd, MainBoard.sch]
2019-04-28 Pullup for displays
    +removed trash
    [MainBoard.brd, MainBoard.sch]
2019-04-28 Fixed wrong encoder reading processing after pressing stop
    [main.c]
2019-04-28 Small corrections in comments and enums
    [main.c]
2019-05-03 Power boards incorporated
    Redrawn power supply circuits so we use one PCB
    [MainBoard.sch]
2019-05-03 Newest Corrected schematic
    Splited into diffrent sheets. Improoved readability.
    [Ekspander.sch, MainBoard.sch]
2019-05-16 Swapped pins 13 and 14
    [AssUpper.0001.iam, AssUpper.iam, Assembly.0001.iam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]
2019-05-16 Vreg done, formatting
    TODO:
    solve offgrid
    check charger circuit if proper
    [MainBoard.brd, MainBoard.sch]
2019-05-19 Buzzer migration, RCK pin change, : behave
    RCK -> PB0
    BUZZER -> OCR1A
    : blink on pause, constant on running
    [buzzer.c, display.c, main.c]
2019-05-23 Prevented pause on finish, added external crystal clock
    [main.c]
2019-05-26 After meeting corrections
    New pause mode
    Brightness map inverted
    Max warning time restricted
    Buzzer fixed
    UART fixed (F_CPU flag changed)
    Pwr Fail procedure delay corrected
    [buzzer.c, main.c, pwrFail.c]
2019-05-31 Updated pinout
    [MainBoard.sch]
2019-10-06 Update MainBoard.sch
    Corrected some values, added descriptions and some typos.
    [MainBoard.sch]
2019-10-12 Minor changes in pin config
2019-10-12 After review corrections
    W programie LEDy od dwukropka sa kropkami dwoch srodkowych wyswietlaczy (wariant w ktorym segmenty wyswietlacza sa obslugiwane przez dwa osobbe rejestry przesuwny jest niekorzystny programowo)
    Light sensor powinien byc podlaczony do PC0 [L1] (olewamy ADC6)
    Czy na pewno podlaczenie TX ATmegi do TX FTDI ma sens? Nie powinno byc crossowania? (oznaczenie TX dotyczy ATmegi)
    Nowe podlaczenie pinow PCF na schematach (nie uzyc pinu P7)
    Usunac przyciski z podswietleniem (przyciskow jest 5), 3 LEDy sygnalizujace wybrana opcje ustawien wlaczane stanem niskim na pinie ATmegi (P1 - P3)
    Przycisk zwierajacy PD7 do masy na schemacie (dodaj do BOMu)
    Czy jest pull-up na PC6 (RESET)?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
    [Ekspander.sch, MainBoard.sch]
2019-10-27 Major board changes
    Remake of interface upper board + layout
    Majior corrections in mainboard - correct models, cables, connectors, ft232 and more. Also more libraries.
    [Ekspander.brd, Ekspander.sch, MainBoard.sch]
2019-10-30 Bootloader problem fix
    Changed initialization order to fix bootloader problem
    [main.c]
2019-11-02 new lib + board progress
    [MainBoard.brd, MainBoard.sch]
2019-11-02 Resistor values updated
    [MainBoard.sch]
2019-11-03 Supply replacements + corrections
    Vreg replaced by pololu board
    Added LDO for VCC supply and moved power on switch
    Protection included into battery cicruit
    Corrected supply of ft232 diodes
    Changed supply of photoresistor to avcc
    [MainBoard.sch]
2019-11-03 7segm lib + board
    Corrections on consistency and erc errors
    readded 7 segm. custom lib
    Partial components placement and routing tries
    [MainBoard.brd, MainBoard.sch]
2019-11-07 libs actualisation + drc rules for expander
    [Ekspander.brd, Ekspander.sch, MainBoard.brd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]
2019-11-07 Consolidation of schematic + lib restore
    [MainBoard.brd, MainBoard.sch]
2019-11-09 Probably final routing of Expander board
    DRC 8mils clean
    libs actualisation
    [Ekspander.brd, Ekspander.sch]
2019-11-09 Drc corrections
    Expander board finished:
    DRC 10mils chcecked except gaps between close pads in connector and usb
    in connector and usb drc 8mils passed
    [Ekspander.brd]
2019-11-12 lib update + board ongoing
    [Ekspander.brd, MainBoard.brd, MainBoard.sch]
2019-11-12 PCB with original pinout
    Register inputs unconnected but drawn close
    Not every path has optimal width
    [MainBoard.brd, MainBoard.sch]
2019-11-14 Final packages
    +most paths wider (24 mils)
    [Ekspander.brd, Ekspander.sch, MainBoard.brd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]
2019-11-14 Mixing led signals
    [MainBoard.brd, MainBoard.sch]
2019-11-14 rotation of tape ports
    also some nets wider
    [Ekspander.brd, Ekspander.sch, MainBoard.brd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]
2019-11-15 Almost complete
    Added 3d extraction
    wider better paths
    corrected Temperature field of TP to be GND
    [MainBoard.brd, MainBoard.sch]
2019-11-15 Corrected programmer pins
    + added full inventor 3d model with most important dimensions
    [MainBoard.brd]
2019-11-17 Pools of gnd
    + change of lib gnd of mechanical hold
    + logos
    [MainBoard.brd, MainBoard.sch]
2019-11-17 Revert "Pools of gnd"
    This reverts commit 4498ba5dce1e14fe788b06c680ced1a0feefa50f.
    [MainBoard.brd, MainBoard.sch]
2019-11-17 Revert "Revert "Pools of gnd""
    This reverts commit 2f73202806bed85f49afe26d98c16d19bdefccd4.
    [MainBoard.brd, MainBoard.sch]
2019-11-17 Add Logos
    add pads for tape connector
2019-11-17 Revert pools
    +Corrected isostat
    [MainBoard.brd, MainBoard.sch]
2019-11-17 Mainboard Top gnd plane
    [MainBoard.brd]
2019-11-17 Main board gnd bottom pool
    [MainBoard.brd, MainBoard.sch]
2019-11-17 expander pools
    [Ekspander.brd, Ekspander.sch]
2019-11-18 Logos incorpoarted
    +gerbers generated
    [Ekspander.brd, MainBoard.brd]
2019-11-21 Many final changes
    [Ekspander.brd, Ekspander.sch, MainBoard.brd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]
2019-12-13 Target board programming preparation
2019-12-15 Adjusted code for PCB prototype
2020-01-10 Final actualisation
    Libs update
    Change name from Ekspander to Interface
    [Interface.brd, Interface.sch, Lista komponentów.xlsx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]
2020-02-08 Added 20s alarm timeout & light sensor filtration

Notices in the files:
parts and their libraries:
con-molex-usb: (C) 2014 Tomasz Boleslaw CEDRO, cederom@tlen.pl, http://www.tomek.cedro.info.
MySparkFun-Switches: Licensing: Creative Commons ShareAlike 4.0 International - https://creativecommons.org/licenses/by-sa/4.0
